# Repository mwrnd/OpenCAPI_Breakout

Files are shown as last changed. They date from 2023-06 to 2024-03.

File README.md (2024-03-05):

# OpenCAPI Breakout

[OpenCAPI](https://files.openpower.foundation/s/xSQPe6ypoakKQdq/download/25Gbps-spec-20171108.pdf) to [U.FL/UMCC Connector](https://en.wikipedia.org/wiki/Hirose_U.FL) breakout.

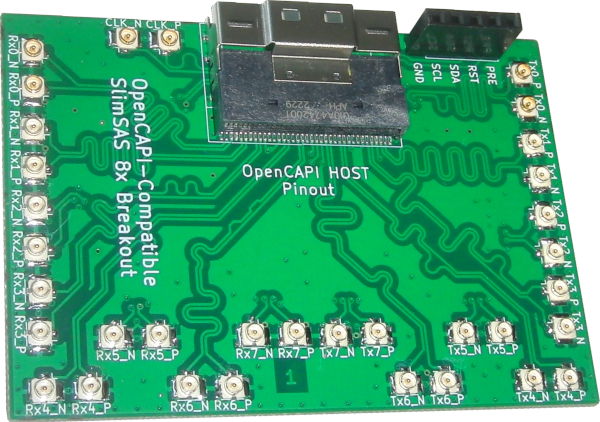
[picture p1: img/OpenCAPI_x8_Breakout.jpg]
OpenCAPI SlimSAS 8x Breakout


I have [successfully tested](https://github.com/mwrnd/innova2_experiments/tree/main/xdma_opencapi) the board using [3M 8ES8-1DF21](https://www.trustedparts.com/en/search/8ES8-1DF21-0.75)([Datasheet](https://multimedia.3m.com/mws/media/1398233O/3m-slimline-twin-ax-assembly-sff-8654-x8-30awg-78-5100-2665-8.pdf)) and
 [SlimSAS SFF-8654 8i 85-Ohm](https://www.sfpcables.com/24g-internal-slimsas-sff-8654-to-sff-8654-8i-cable-straight-to-90-degree-left-angle-8x-12-sas-4-0-85-ohm-0-5-1-meter)([Archived](https://web.archive.org/web/20210121175017/https://www.sfpcables.com/24g-internal-slimsas-sff-8654-to-sff-8654-8i-cable-straight-to-90-degree-left-angle-8x-12-sas-4-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)) cables. The 3M Cable has better performance.

No consideration was given to pinout compatibility with the [SlimSAS SFF-8654 Standard](https://members.snia.org/document/dl/26744).

The [Open Coherant Accelerator Processor Interface](https://opencapi.org/wp-content/uploads/2022/07/OpenCAPI-Overview.pdf) (OpenCAPI) [was a standard](https://opencapi.org/2022/08/09/cxl-consortium-and-opencapi-consortium-sign-letter-of-intent-to-transfer-opencapi-specifications-to-cxl/) that had FPGA-based [Advanced Accelerated Cable](https://files.openpower.foundation/s/xSQPe6ypoakKQdq/download/25Gbps-spec-20171108.pdf) (AAC) [Add-In cards](https://opencapi.org/wp-content/uploads/2018/12/OpenCAPI-Tech-SC18-Exhibitor-Forum.pdf) such as [ADM-PCIE-9H3](https://www.alpha-data.com/product/adm-pcie-9h3/), [ADM-PCIE-9H7](https://www.alpha-data.com/alpha-data-release-adm-pcie-9h7-data-center-board-with-xilinx-virtex-ultrascale-hbm-fpga/), [ADM-PCIE-9V3](https://www.alpha-data.com/product/adm-pcie-9v3/), [ADM-PCIE-9V5](https://www.alpha-data.com/product/adm-pcie-9v5/), [BittWare XUPSVH](https://static5.arrow.com/pdfs/2018/10/26/23/28/4/364872/btwr_/manual/ds-xupsvh.pdf), [BittWare XUP-VV4](https://www.bittware.com/fpga/xup-vv4/), [BittWare XUP-VVH](https://www.bittware.com/fpga/xup-vvh/), and [Nvidia Innova-2 Flex](https://www.nvidia.com/en-us/networking/ethernet/innova-2-flex/).

Related Projects: [PCIe_x8_Breakout](https://github.com/mwrnd/PCIe_x8_Breakout), [OpenCAPI-to-PCIe](https://github.com/mwrnd/OpenCAPI-to-PCIe), [OpenCAPI-to-PCIe_x4_Host_and_Endpoint](https://github.com/mwrnd/OpenCAPI-to-PCIe_x4_Host_and_Endpoint), [QSFP_Breakout](https://github.com/mwrnd/QSFP_Breakout), [HDMI_Breakout](https://github.com/mwrnd/HDMI_Breakout), [SFP_Plug_Breakout](https://github.com/mwrnd/SFP_Plug_Breakout)

# Testing and Use Example

This board can be used along with a [PCIe_x8_Breakout](https://github.com/mwrnd/PCIe_x8_Breakout) board to test [OpenCAPI-to-PCIe](https://github.com/mwrnd/innova2_experiments/tree/main/xdma_opencapi) on the [Innova-2 SmartNIC](https://www.nvidia.com/en-us/networking/ethernet/innova-2-flex/). PCIe 3.0 x4 at 8.0GT/s works. Standard [0.1" M-F Jumpers](https://www.digikey.com/en/products/detail/adafruit-industries-llc/1954/6827087) are used for the PCIe Reset Signal (*nPERST*) and its GND.

With cables shorter than 100mm~=4" the [adapters work](https://github.com/mwrnd/innova2_experiments/tree/main/xdma_opencapi). The [RX U.FL-to-U.FL cables](https://www.digikey.com/en/products/detail/te-connectivity-amp-connectors/2118651-6/11205742) are all the same length as each other and likewise all [TX cables](https://www.digikey.com/en/products/detail/te-connectivity-amp-connectors/2015698-2/1249186) are the same length but RX and TX are different lengths as that is what I had available. RX on the PCIe board connects to RX on the OpenCAPI board as it uses the OpenCAPI Host pinout.

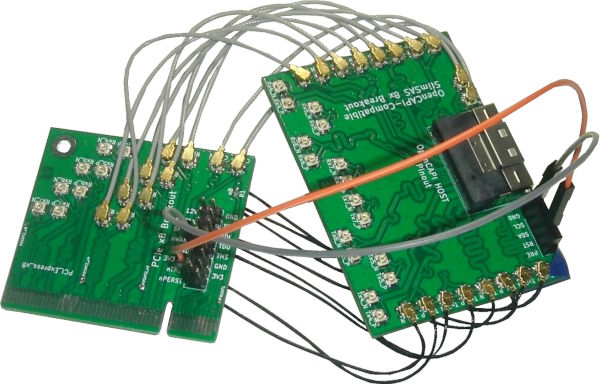
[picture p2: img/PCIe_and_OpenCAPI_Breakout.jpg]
PCIe x8 Breakout and OpenCAPI Breakout


PCIe x4 In-system:

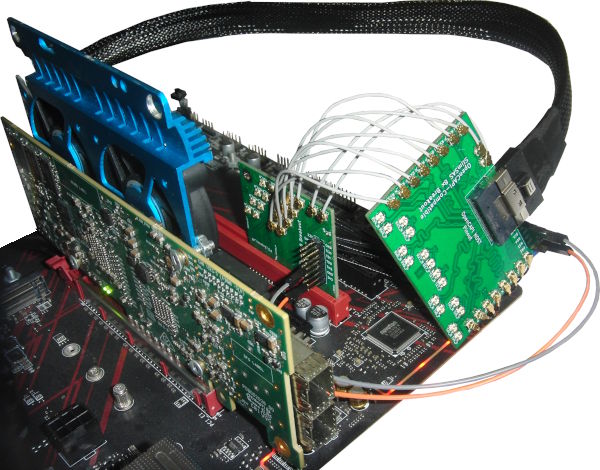
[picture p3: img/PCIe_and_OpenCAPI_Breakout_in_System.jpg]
PCIe x8 Breakout and OpenCAPI Breakout In System


However, using 250mm IPEX cables the adapters fail for PCIe x8:

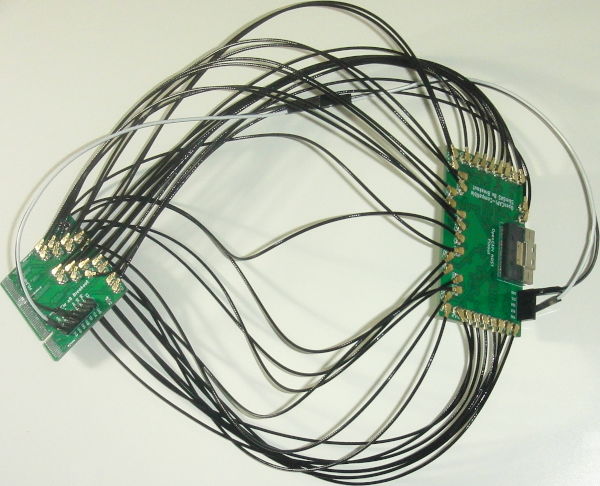
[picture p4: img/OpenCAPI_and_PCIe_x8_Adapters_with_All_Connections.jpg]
PCIe x8 Breakout and OpenCAPI Breakout All Connections


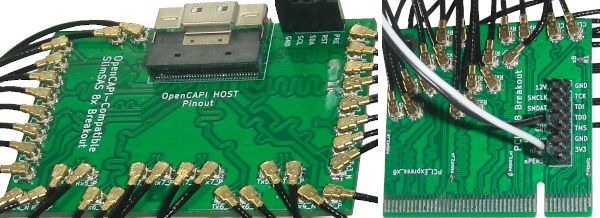
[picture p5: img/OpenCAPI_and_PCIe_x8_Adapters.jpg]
Adapters Close-up


PCIe x8 In-system:

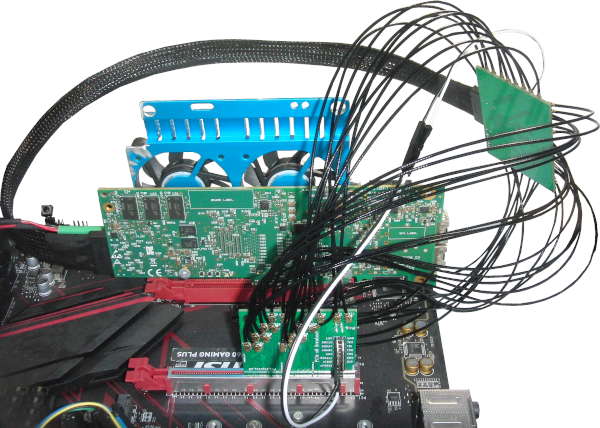
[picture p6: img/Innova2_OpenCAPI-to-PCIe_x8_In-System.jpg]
OpenCAPI to PCIe x8 In-System


# First Revision

Main difference between the First and Second Revisions is their silkscreen labelling. Both are based on the pinout from the [ADM-PCIE-9V5 User Manual (Pg15-19of38)](https://www.alpha-data.com/xml/user_manuals/adm-pcie-9v5%20user%20manual_v1_4.pdf).

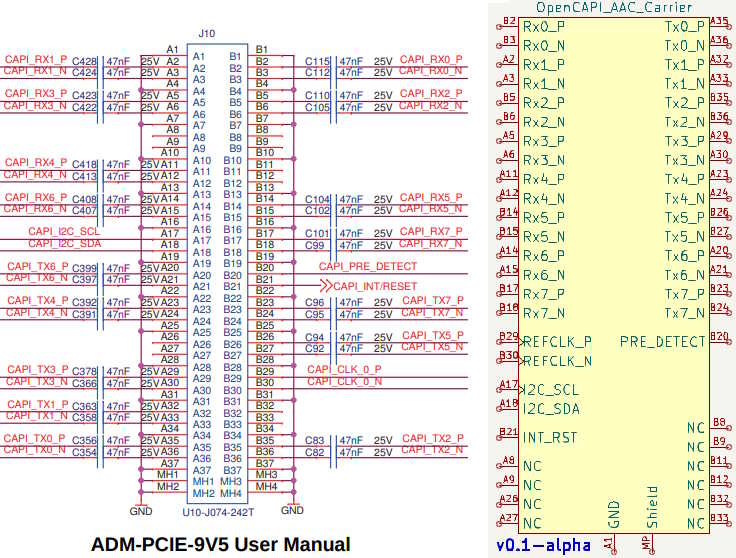
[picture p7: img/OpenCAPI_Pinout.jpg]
OpenCAPI Pinout


The First Revision uses the OpenCAPI **Host** pinout which is the row A-to-B/B-to-A swapped version of the **Carrier** pinout that is used on OpenCAPI AAC Add-In cards. When used with a [PCIe_x8_Breakout](https://github.com/mwrnd/PCIe_x8_Breakout) **Rx** signals connect to **Rx** and **Tx** to **Tx**.

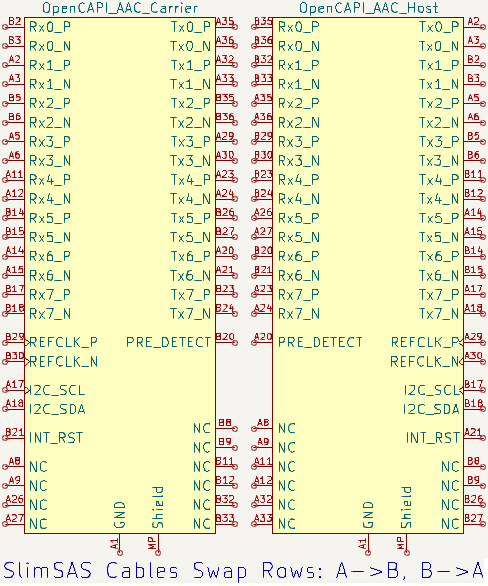
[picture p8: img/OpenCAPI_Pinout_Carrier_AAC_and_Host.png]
OpenCAPI Pinout Carrier AAC and Host


Labels are relative to the Host. Host RX is Carrier TX and vice versa so the **Rx** pins on this board have transmitter signals from the Add-in card on them. **Tx** pins connect to the Add-in card's receiver signals.

## PCB Layout

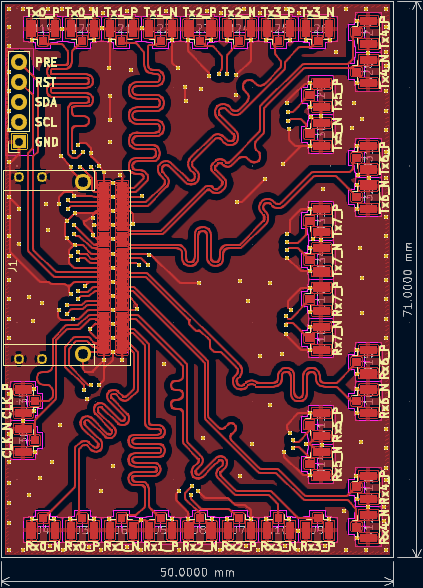
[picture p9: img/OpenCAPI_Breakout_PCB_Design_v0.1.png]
OpenCAPI Breakout PCB Layout First Revision


## Schematic

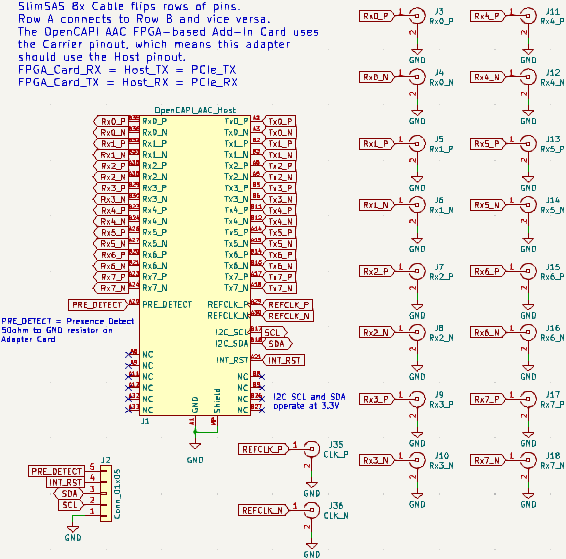
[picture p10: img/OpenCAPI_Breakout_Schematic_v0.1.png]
OpenCAPI Breakout Schematic First Revision


# Second Revision

The Second Revision changes the silkscreen to label the U.FL connectors with the signal that is on them. **Tx** pins connect to the Add-In card's transmitter pins and **Rx** signals connect to receiver pins.

The board also annotates the corresponding GTY channels when connected to an MNV303212A Rev.A2 board. The MNV303212A's [swapped differential pairs](https://github.com/mwrnd/innova2_flex_xcku15p_notes/tree/main/hardware_notes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) are also annotated.

When used with a [PCIe_x8_Breakout](https://github.com/mwrnd/PCIe_x8_Breakout) **Rx** signals connect to PCIe **Tx** and **Tx** to **Rx**.

## PCB Layout

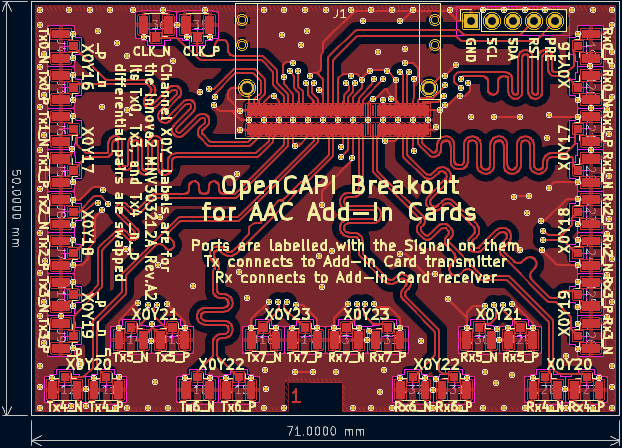
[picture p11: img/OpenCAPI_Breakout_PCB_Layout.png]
OpenCAPI Breakout PCB Layout Second Revision


## Schematic

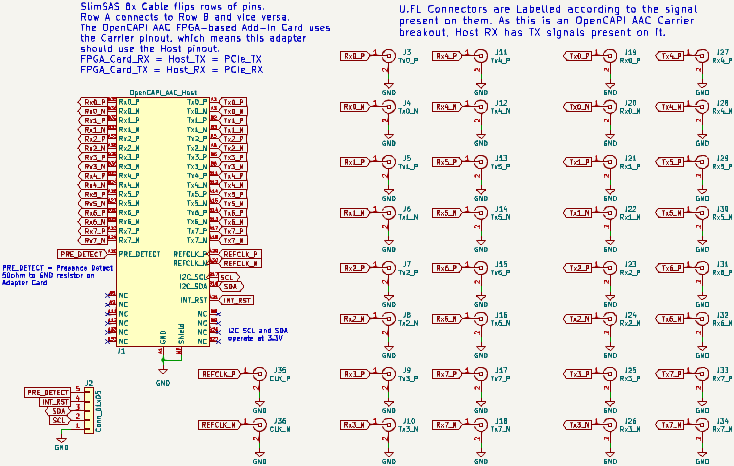
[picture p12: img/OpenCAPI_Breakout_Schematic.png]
OpenCAPI Breakout Schematic Second Revision


# Design Notes

All differential pairs are length-matched to within 1mm both inter-pair and intra-pair.

The board requires a [U10A474200T](https://www.digikey.com/en/products/detail/amphenol-cs-commercial-products/U10A474200T/14632855)/[U10A474240T](https://www.digikey.com/en/products/detail/amphenol-cs-commercial-products/U10A474240T/17066204) SlimSAS 74-Pin Receptacle, up to 34 [U.FL/UMCC Surface Mount Receptacles](https://www.digikey.com/en/products/detail/te-connectivity-amp-connectors/2337019-1/9974052), and a 5-Pin 2.54mm [Header](https://www.digikey.com/en/products/detail/sullins-connector-solutions/PREC005SAAN-RC/2774849) or [Socket](https://www.digikey.com/en/products/detail/sullins-connector-solutions/PPPC051LFBN-RC/810177).

## PCB Layer Stackup

4-Layer PCB stackup taken from [JLCPCB](https://jlcpcb.com/capabilities/pcb-capabilities).

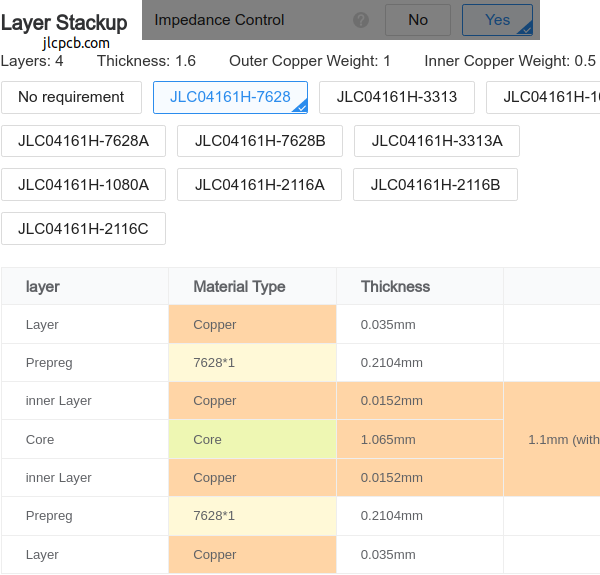
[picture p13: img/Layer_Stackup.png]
PCB Layer Stackup


Differential Impedance parameters were calculated using the [DigiKey Online Calculator](https://www.digikey.com/en/resources/conversion-calculators/conversion-calculator-pcb-trace-impedance).

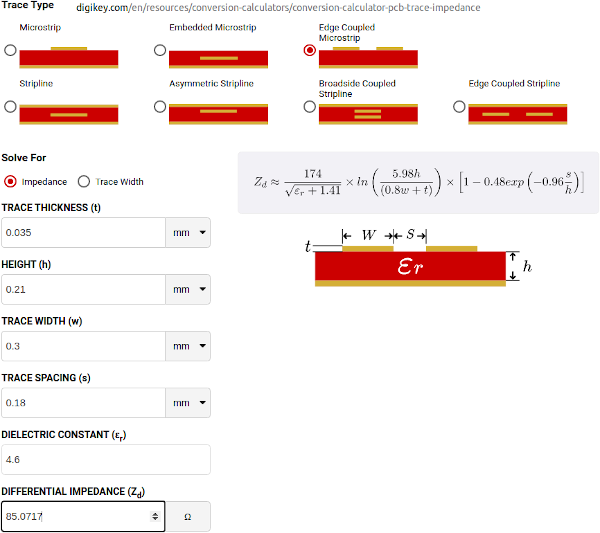
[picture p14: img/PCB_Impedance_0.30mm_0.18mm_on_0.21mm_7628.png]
PCB Differential Impedance Calculation


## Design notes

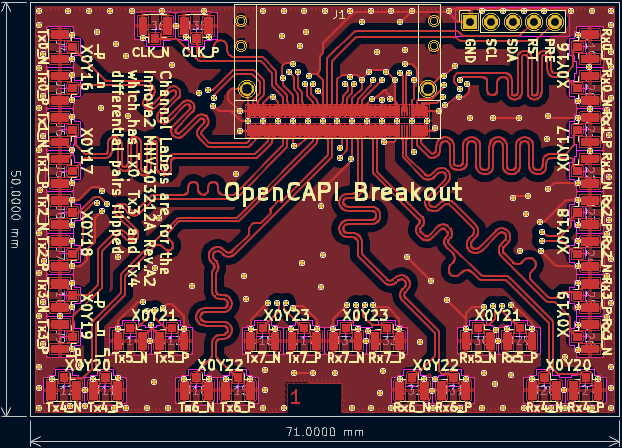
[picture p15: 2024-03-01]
img/OpenCAPI_Breakout_PCB_Design.png

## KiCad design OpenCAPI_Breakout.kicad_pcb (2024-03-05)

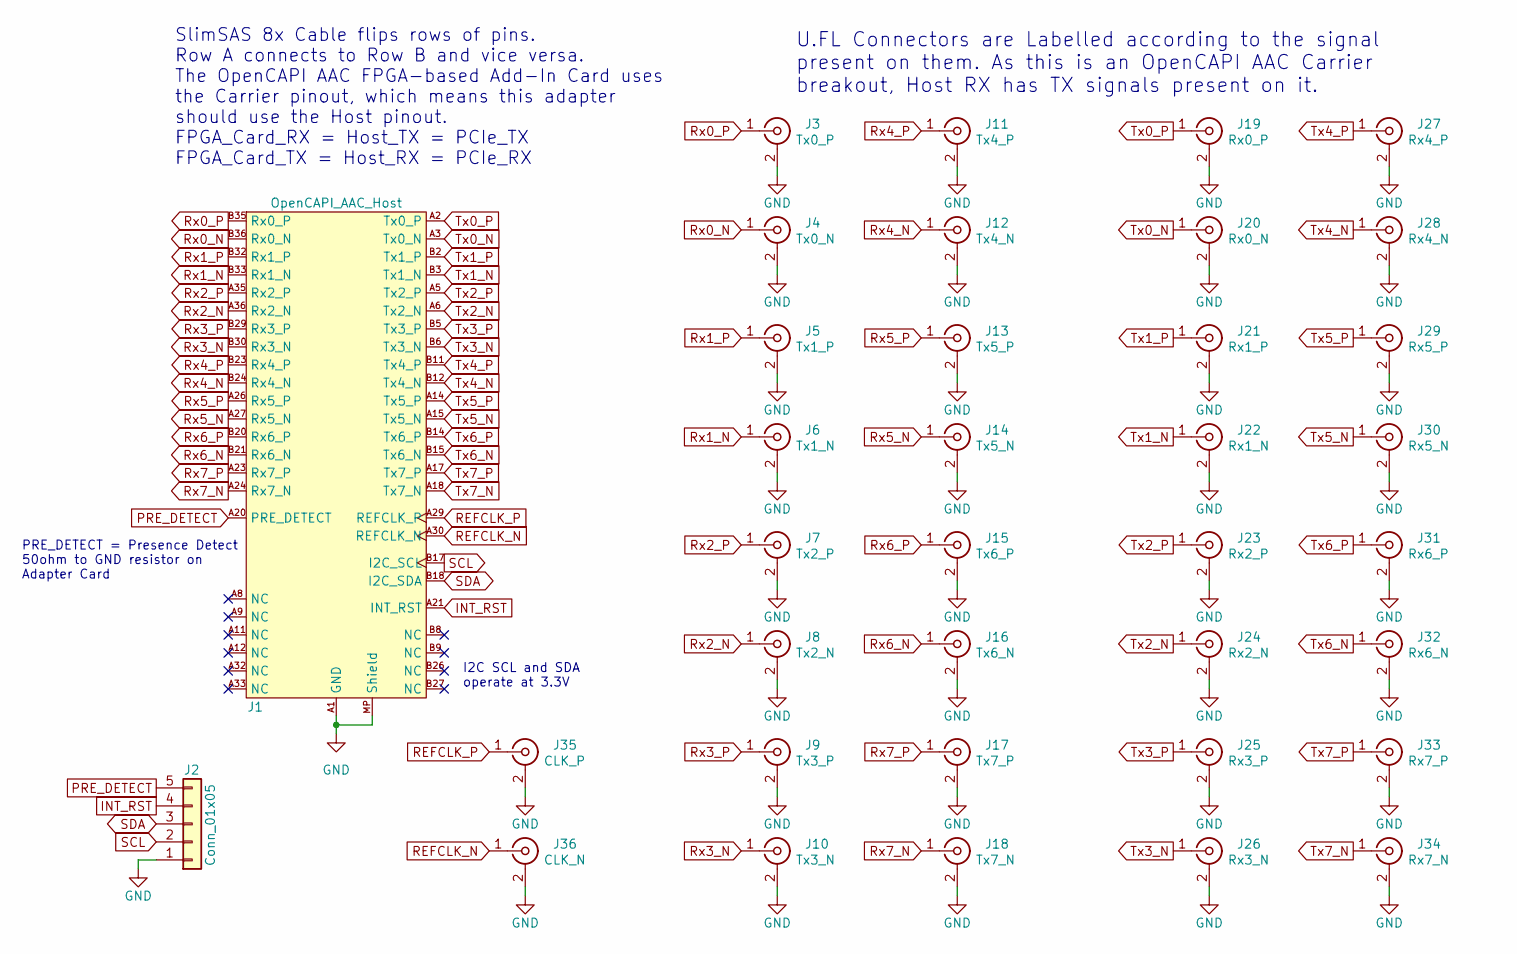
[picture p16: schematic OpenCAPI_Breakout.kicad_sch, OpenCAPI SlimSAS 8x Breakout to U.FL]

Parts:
J1: OpenCAPI_AAC_Host; SlimSAS_8x_RA_U10-A474
J2: Conn_01x05; PinSocket_1x05_P2.54mm_Vertical
J3: Tx0_P; U.FL_Hirose_w_Label
J4: Tx0_N; U.FL_Hirose_w_Label
J5: Tx1_P; U.FL_Hirose_w_Label
J6: Tx1_N; U.FL_Hirose_w_Label
J7: Tx2_P; U.FL_Hirose_w_Label
J8: Tx2_N; U.FL_Hirose_w_Label
J9: Tx3_P; U.FL_Hirose_w_Label
J10: Tx3_N; U.FL_Hirose_w_Label
J11: Tx4_P; U.FL_Hirose_w_Label
J12: Tx4_N; U.FL_Hirose_w_Label
J13: Tx5_P; U.FL_Hirose_w_Label
J14: Tx5_N; U.FL_Hirose_w_Label
J15: Tx6_P; U.FL_Hirose_w_Label
J16: Tx6_N; U.FL_Hirose_w_Label
J17: Tx7_P; U.FL_Hirose_w_Label
J18: Tx7_N; U.FL_Hirose_w_Label
J19: Rx0_P; U.FL_Hirose_w_Label
J20: Rx0_N; U.FL_Hirose_w_Label
J21: Rx1_P; U.FL_Hirose_w_Label
J22: Rx1_N; U.FL_Hirose_w_Label
J23: Rx2_P; U.FL_Hirose_w_Label
J24: Rx2_N; U.FL_Hirose_w_Label
J25: Rx3_P; U.FL_Hirose_w_Label
J26: Rx3_N; U.FL_Hirose_w_Label
J27: Rx4_P; U.FL_Hirose_w_Label
J28: Rx4_N; U.FL_Hirose_w_Label
J29: Rx5_P; U.FL_Hirose_w_Label
J30: Rx5_N; U.FL_Hirose_w_Label
J31: Rx6_P; U.FL_Hirose_w_Label
J32: Rx6_N; U.FL_Hirose_w_Label
J33: Rx7_P; U.FL_Hirose_w_Label
J34: Rx7_N; U.FL_Hirose_w_Label
J35: CLK_P; U.FL_Hirose_w_Label
J36: CLK_N; U.FL_Hirose_w_Label

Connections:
GND: J1.A1 (GND), J1.A4 (GND), J1.A7 (GND), J1.A10 (GND), J1.A13 (GND), J1.A16 (GND), J1.A19 (GND), J1.A22 (GND), J1.A25 (GND), J1.A28 (GND), J1.A31 (GND), J1.A34 (GND), J1.A37 (GND), J1.B1 (GND), J1.B4 (GND), J1.B7 (GND), J1.B10 (GND), J1.B13 (GND), J1.B16 (GND), J1.B19 (GND), J1.B22 (GND), J1.B25 (GND), J1.B28 (GND), J1.B31 (GND), J1.B34 (GND), J1.B37 (GND), J1.MP (Shield), J2.1, J3.2 (Ext), J4.2 (Ext), J5.2 (Ext), J6.2 (Ext), J7.2 (Ext), J8.2 (Ext), J9.2 (Ext), J10.2 (Ext), J11.2 (Ext), J12.2 (Ext), J13.2 (Ext), J14.2 (Ext), J15.2 (Ext), J16.2 (Ext), J17.2 (Ext), J18.2 (Ext), J19.2 (Ext), J20.2 (Ext), J21.2 (Ext), J22.2 (Ext), J23.2 (Ext), J24.2 (Ext), J25.2 (Ext), J26.2 (Ext), J27.2 (Ext), J28.2 (Ext), J29.2 (Ext), J30.2 (Ext), J31.2 (Ext), J32.2 (Ext), J33.2 (Ext), J34.2 (Ext), J35.2 (Ext), J36.2 (Ext)
INT_RST: J1.A21 (INT_RST), J2.4
PRE_DETECT: J1.A20 (PRE_DETECT), J2.5
REFCLK_N: J1.A30 (REFCLK_N), J36.1 (In)
REFCLK_P: J1.A29 (REFCLK_P), J35.1 (In)
Rx0_N: J1.B36 (Rx0_N), J4.1 (In)
Rx0_P: J1.B35 (Rx0_P), J3.1 (In)
Rx1_N: J1.B33 (Rx1_N), J6.1 (In)
Rx1_P: J1.B32 (Rx1_P), J5.1 (In)
Rx2_N: J1.A36 (Rx2_N), J8.1 (In)
Rx2_P: J1.A35 (Rx2_P), J7.1 (In)
Rx3_N: J1.B30 (Rx3_N), J10.1 (In)
Rx3_P: J1.B29 (Rx3_P), J9.1 (In)
Rx4_N: J1.B24 (Rx4_N), J12.1 (In)
Rx4_P: J1.B23 (Rx4_P), J11.1 (In)
Rx5_N: J1.A27 (Rx5_N), J14.1 (In)
Rx5_P: J1.A26 (Rx5_P), J13.1 (In)
Rx6_N: J1.B21 (Rx6_N), J16.1 (In)
Rx6_P: J1.B20 (Rx6_P), J15.1 (In)
Rx7_N: J1.A24 (Rx7_N), J18.1 (In)
Rx7_P: J1.A23 (Rx7_P), J17.1 (In)
SCL: J1.B17 (I2C_SCL), J2.2
SDA: J1.B18 (I2C_SDA), J2.3
Tx0_N: J1.A3 (Tx0_N), J20.1 (In)
Tx0_P: J1.A2 (Tx0_P), J19.1 (In)
Tx1_N: J1.B3 (Tx1_N), J22.1 (In)
Tx1_P: J1.B2 (Tx1_P), J21.1 (In)
Tx2_N: J1.A6 (Tx2_N), J24.1 (In)
Tx2_P: J1.A5 (Tx2_P), J23.1 (In)
Tx3_N: J1.B6 (Tx3_N), J26.1 (In)
Tx3_P: J1.B5 (Tx3_P), J25.1 (In)
Tx4_N: J1.B12 (Tx4_N), J28.1 (In)
Tx4_P: J1.B11 (Tx4_P), J27.1 (In)
Tx5_N: J1.A15 (Tx5_N), J30.1 (In)
Tx5_P: J1.A14 (Tx5_P), J29.1 (In)
Tx6_N: J1.B15 (Tx6_N), J32.1 (In)
Tx6_P: J1.B14 (Tx6_P), J31.1 (In)
Tx7_N: J1.A18 (Tx7_N), J34.1 (In)
Tx7_P: J1.A17 (Tx7_P), J33.1 (In)

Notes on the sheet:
I2C SCL and SDA operate at 3.3V
SlimSAS 8x Cable flips rows of pins. Row A connects to Row B and vice versa. The OpenCAPI AAC FPGA-based Add-In Card uses the Carrier pinout, which means this adapter should use the Host pinout. FPGA_Card_RX = Host_TX = PCIe_TX FPGA_Card_TX = Host_RX = PCIe_RX
U.FL Connectors are Labelled according to the signal present on them. As this is an OpenCAPI AAC Carrier breakout, Host RX has TX signals present on it.
PRE_DETECT = Presence Detect 50ohm to GND resistor on Adapter Card

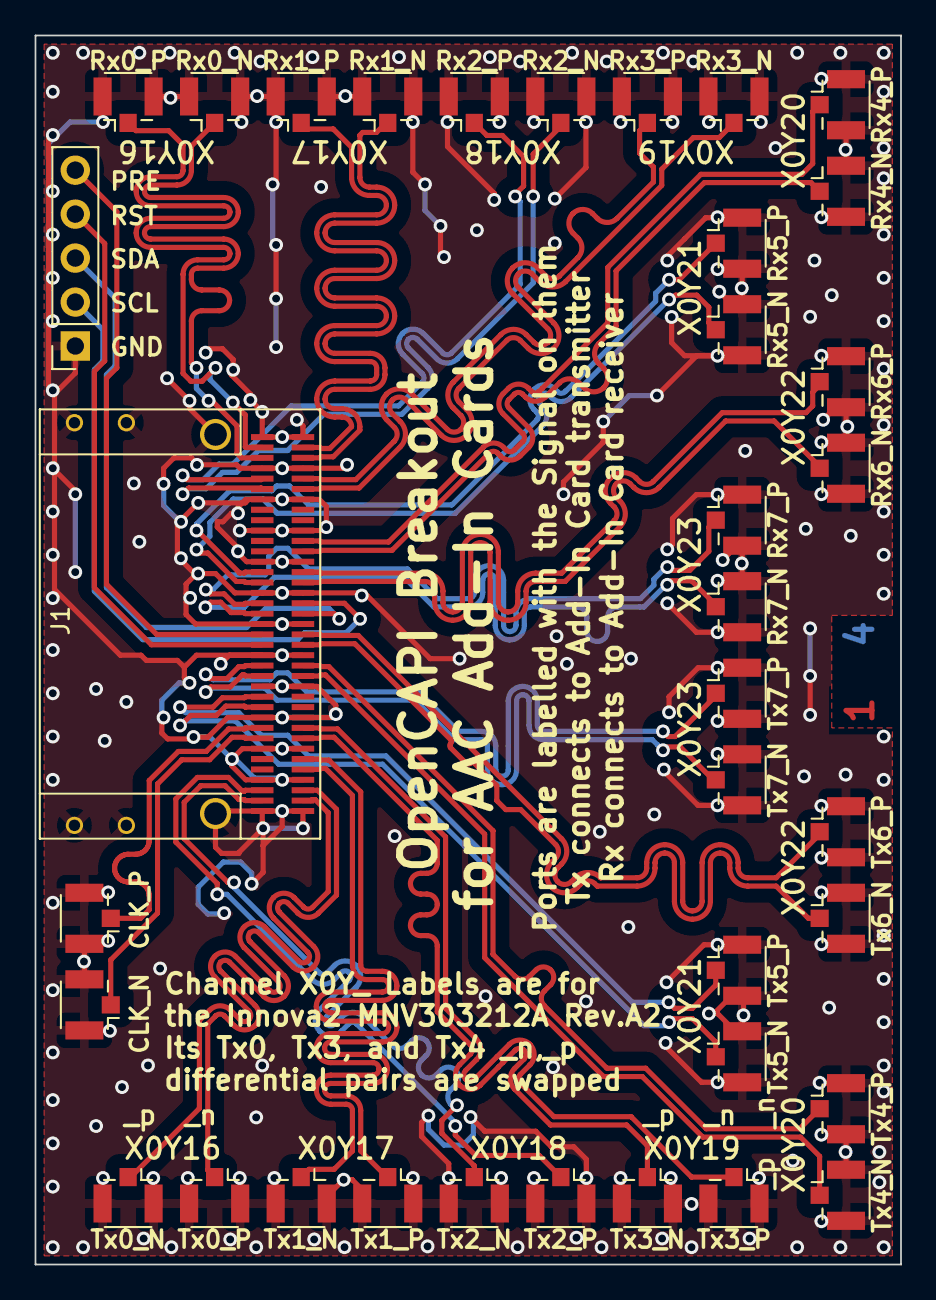
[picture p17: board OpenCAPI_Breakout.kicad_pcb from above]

Board: 4 copper layers, 50.0 x 71.0 mm, 36 parts (0 on the bottom side), 39 nets.

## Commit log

2023-06-10 First Revision
    [SlimSAS8x_Breakout.kicad_pcb, SlimSAS8x_Breakout.kicad_sch]
2023-11-12 Completed Rename
    [SlimSAS8x_Breakout.kicad_pcb, SlimSAS8x_Breakout.kicad_sch]
2024-03-05 Second Revision
    [OpenCAPI_Breakout.kicad_pcb, OpenCAPI_Breakout.kicad_sch]
